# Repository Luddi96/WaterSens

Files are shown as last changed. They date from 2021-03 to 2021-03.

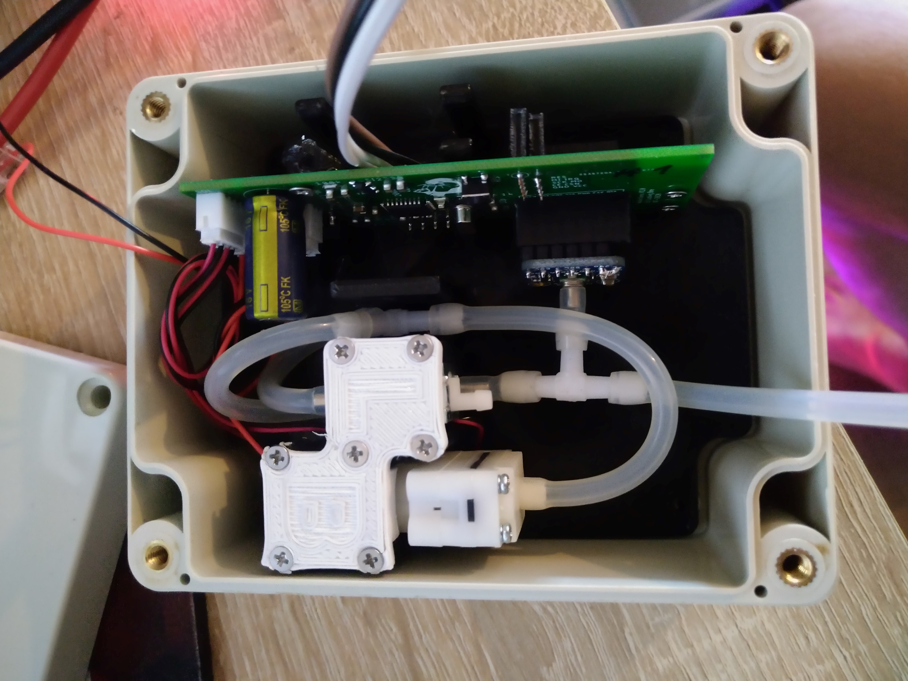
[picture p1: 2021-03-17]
Images/IMG_20200821_111729.jpg

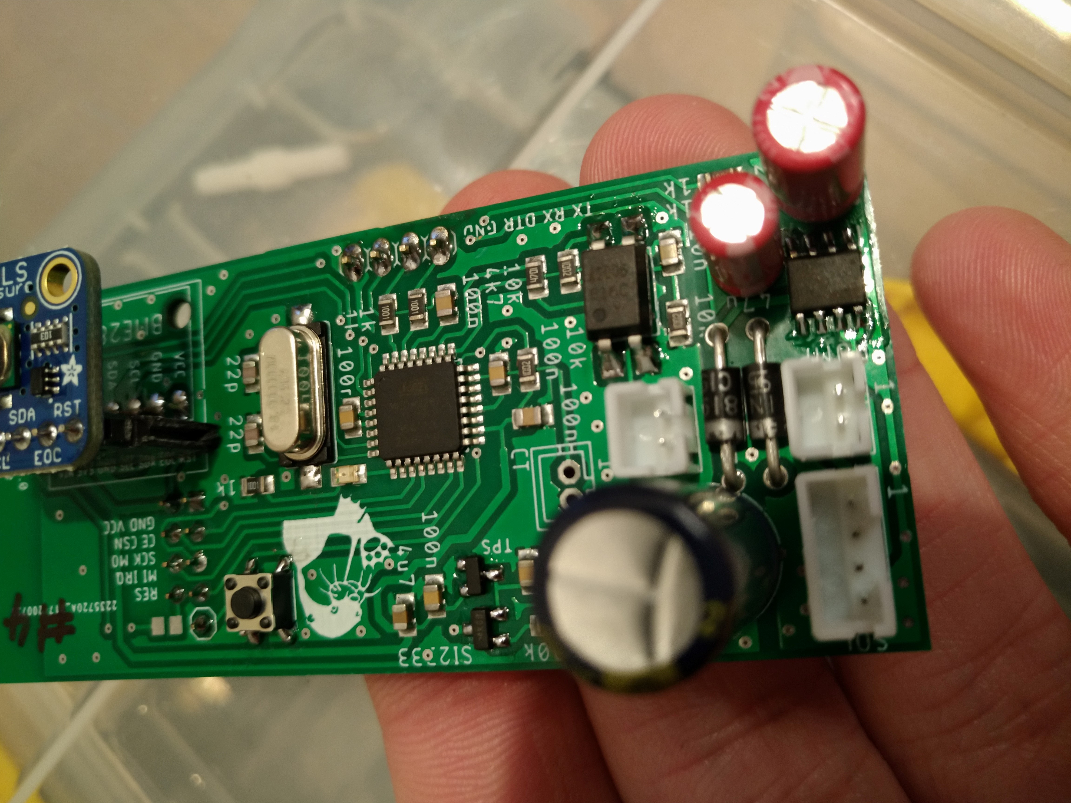
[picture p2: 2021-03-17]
Images/IMG_20210317_152724.jpg

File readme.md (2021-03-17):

Universaler Zisternen-Füllstandsmesser

Einleitung:

Jeder Besitzer einer Regenzisterne kennt diese Frage: Wie viel Wasser verbleibt mir noch und wie viel hat der letzte Regen wieder aufgefüllt? Um Abhilfe zu schaffen gibt es eine Reihe an Messgeräten und Sensoren: Ganz simpel mit mehren Elektroden auf verschiedenen Höhen, kapazitiv unter Zuhilfenahme der Dielektrizitätskonstante des Wassers selbst, per Ultraschall oder per Druckmessung. Einige dieser Messungen haben Vorteile gegenüber anderen. In diesem Beitrag möchte ich Ihnen eine Methode zur Messung vorstellen, welche weder durch Temperatur, Luftdruck oder Leitfähigkeit des Wassers verfälscht wird und außerdem selbstreinigend (wartungsfrei) agiert. Die Messgenauigkeit liegt bei umgerechnet 20 Liter in einer 7500 Liter Zisterne, also etwa 0,3%!
Das Projekt involviert die Programmierung eines ATMega Mikrocontrollers, das Löten von SMD Bauteilen (es könnte aber auch als THT aufgebaut werden) sowie grundlegende mechanische Fähigkeiten.
Das Funktionsprinzip:
Wie funktioniert der Sensor? Im Prinzip ganz einfach: Man misst den Druck, den das Wasser an der tiefsten Stelle der Zisterne erzeugt. Dieser ist proportional zur Höhe des Wassers und somit (bei einer gleichförmigen Zisterne) ebenfalls proportional zum Füllstand. Würde man aber einfach einen Sensor auf den Grund der Zisterne herablassen, so stößt man auf 3 Probleme: 1. Solche Sensoren sind recht teuer (müssen ja auch wasserdicht sein) 2. Es gibt keine Möglichkeit, den Sensor periodisch zu nullen 3. Der Luftdruck beeinflusst das Ergebnis: 10hPa Druckunterschied bedeuten bereits 100mm Wassersäule oder einen Messfehler von etwa 750 Liter in bzw. 10% in einer 7500 Liter Zisterne.
Mit einem Trick können aber alle der eben genannten Einflüsse kompensiert werden: In die Zisterne wird lediglich ein dünner Schlauch mit einem Gewicht am offenen Ende eingeführt und bis zum Boden herabgelassen. In das andere Ende wird mit einer kleinen Luftpumpe so lange Luft gepumpt, bis dieser komplett gefüllt ist und erste Luftblasen austreten. Der Druck im Schlauch entspricht dann genau dem Druck am Boden der Zisterne. Mit einem empfindlichen Drucksensor kann dieser dann ausgelesen werden. Wenn der Schlauch vor und nach der Messung mittels einem Magnetventil entleert wird, können Umgebungsdruck und Langzeit-Drift des Drucksensor eliminiert werden. Ebenso ist das System durch das "Ausspülen" des Schlauches bei jeder Messung selbstreinigend.

Komponenten:

1x Miniatur-Luftpumpe JQB031 oder ähnlich https://bit.ly/2ENsoDM
2x 3-Wege Magnetventil DQF2-6A-4 von dyxminipump https://bit.ly/2G6OzFo
1x Schlauch-Verbinder-Sortiment https://bit.ly/31LYU29
1x 50cm Silikonschlauch (2mm ID) https://bit.ly/2QGRM0I
1x 5m Silikonschlauch (4mm ID) https://bit.ly/34PzMJN
1x MPRLS Sensor-Modul https://www.adafruit.com/product/3965
1x Funkmodul, z.B. NRF24L01
1x Hauptleiterplatte, BOM als ZIP im Anhang
1x LiPo Einzelzelle 1000mAh https://bit.ly/2EHX8WZ

Aufbau:

Die Ansteuerung der Pumpe und Magnetventile sowie das Auslesen und Auswerten des Drucksensor und das anschließende Versenden der Daten per Funk übernimmt die Hauptleiterplatte. Auf dieser befindet sich ein ATMega328P-AU, geflasht mit dem Arudino Nano Bootloader. Zur Ansteuerung der Aktoren genügt ein IRF7103. Da der Sensor mehrere Jahre ohne Batteriewechsel auskommen soll, wird zur Spannungsversorgung ein TPS7A05 LDO mit einer Ausgangsspannung von 3,3V und einem Eigenstromverbrauch von nur 1uA verbaut. Auch der Spannungsteiler zur Messung der Batteriespannung wird über einen Optokoppler geschalten. So kommt das Gesamtsystem auf 6uA Sleep-Strom und bis zu 2 Jahre Lebensdauer bei 2 Messungen am Tag.
Die Pumpe sowie Magnetventile werden wie folgt verbunden:

Mit dem ersten Magnetventil kann der Druck aus dem System abgelassen werden, das andere Magnetventil schneidet "Messschlauch" und Drucksensor vom Rest ab, um einen Druckabfall während der Messung zu verhindern.
Das ganze wird auf einem 3D-Druck-Träger (.stl in der zip-Datei enthalten) in ein Modulgehäuse wasserdicht eingebaut. Der Druckausgleich wird mit einem Druckausgleichselement erreicht.
In der Software sieht der Ablauf wie folgt aus:
Initialisierung: Ports, Variablen, etc. initialisieren, Sensorwert auf 0 setzen
Start einer Messung:
-Druck im offenen System 3x messen, Wert als "before" speichern
-Magnetventil 1 schließen, Pumpe aktivieren
-Nach bestimmter Zeit Magnetventil 2 schließen, Pumpe abschalten und Magnetventil 1 wieder öffnen (der Schlauch steht jetzt unter Druck)
-Druck 3x messen, Wert als "high" speichern
-Magnetventil 2 öffnen und Druck entweichen lassen
-Druck 3x messen und als "after" speichern
-Aus before, after und high die Druckdifferenz berechnen, das ist das Ergebnis.
Eine solche Messung dauert etwa 8 Sekunden.
Fazit und Ergebnisse:
Ich habe das System nun schon seit 2 Monaten in Betrieb. Um die Haltbarkeit zu testen habe ich den Messintervall auf 60 Sekunden verringert und insgesamt hat das System bereits über 25.000 Messungen durchgeführt - ohne Probleme. Die Standardabweichung der Messung liegt bei etwa 2,5mm Wassersäule oder 20 Liter bei einer 7500 Liter Zisterne. Mir gefällt das System sehr gut. Ich habe bereits ein weiteres System gebaut, welches bei einem Bekannten eingebaut wird. Dort ersetzen wir das Funkmodul durch ein LAN-Modul, das System wird zudem dauerhaft mit Strom versorgt.

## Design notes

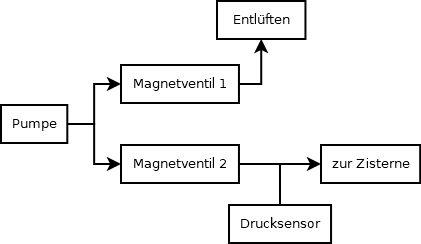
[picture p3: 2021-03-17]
Documentation/Schema.png

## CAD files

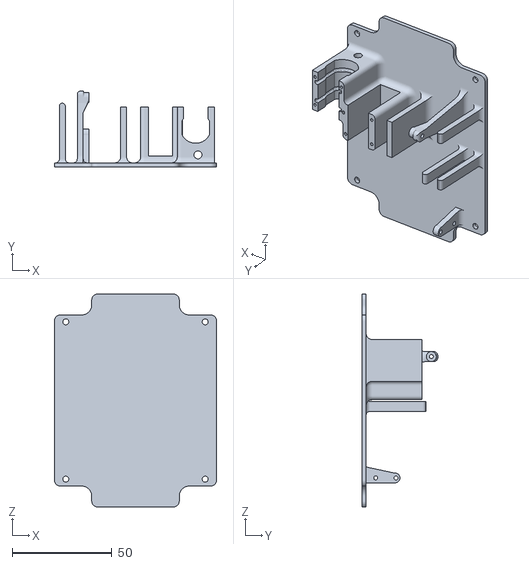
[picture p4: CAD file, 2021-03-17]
Documentation/WaterSensor_V1-1_basic.stl
81.5 x 38.0 x 107.0

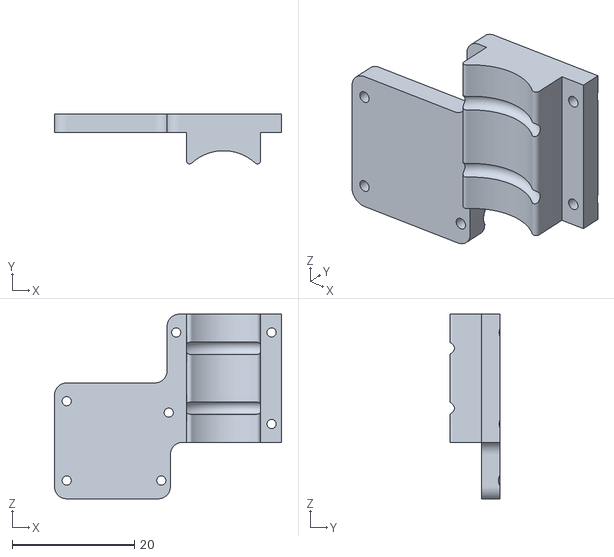
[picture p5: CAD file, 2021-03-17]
Documentation/WaterSensor_V1-0_basic_lid.stl
37.2 x 8.18 x 30.3

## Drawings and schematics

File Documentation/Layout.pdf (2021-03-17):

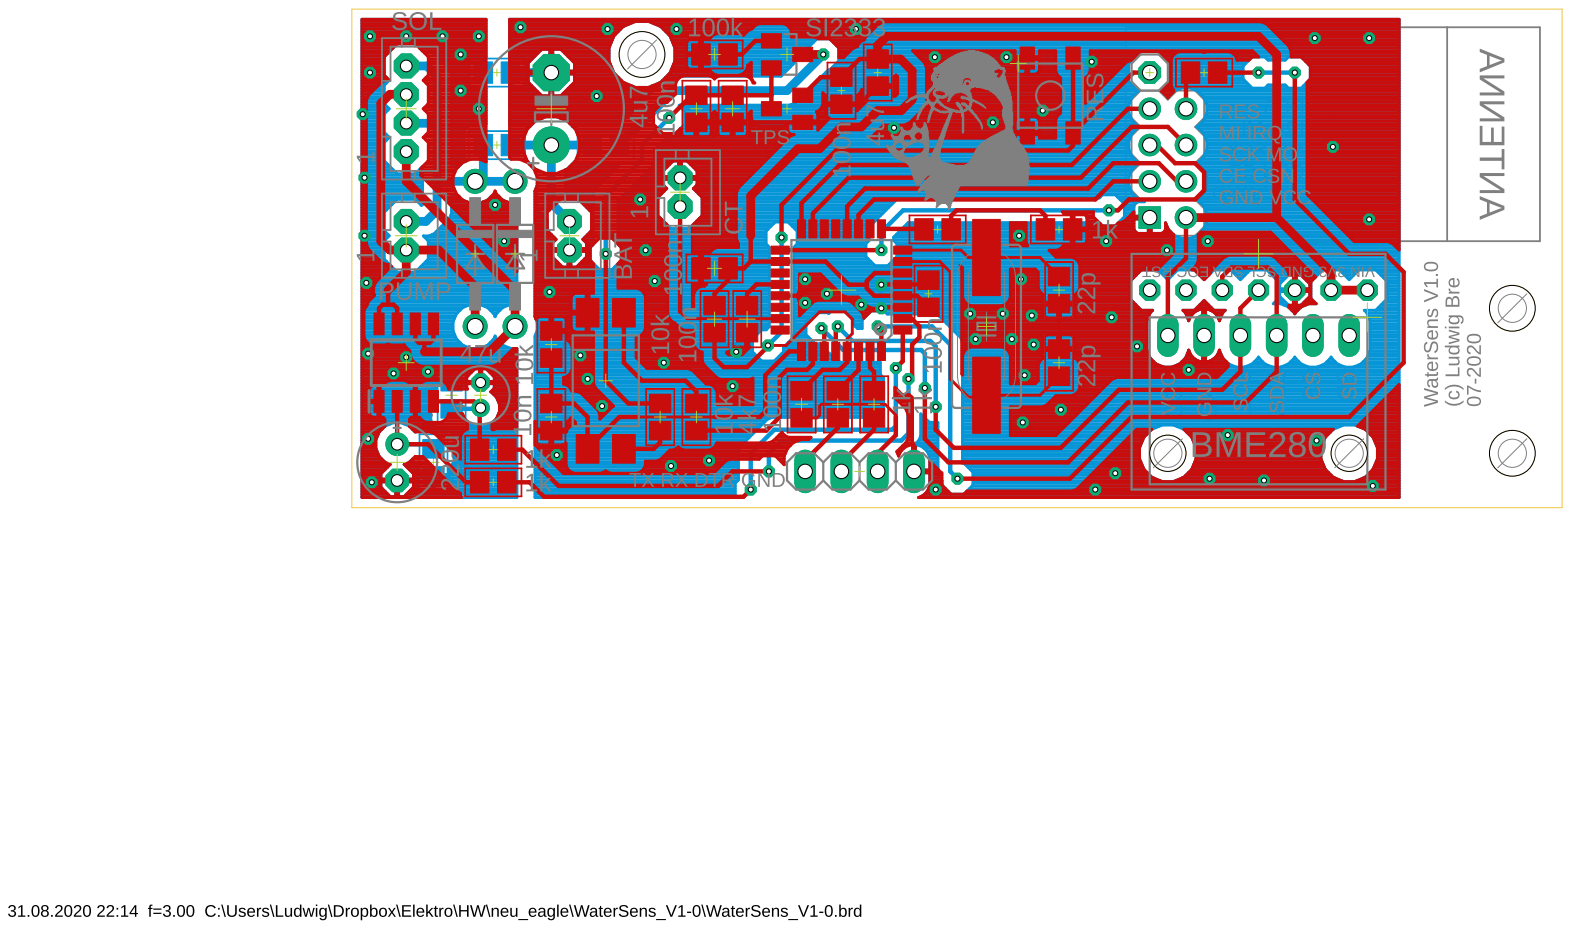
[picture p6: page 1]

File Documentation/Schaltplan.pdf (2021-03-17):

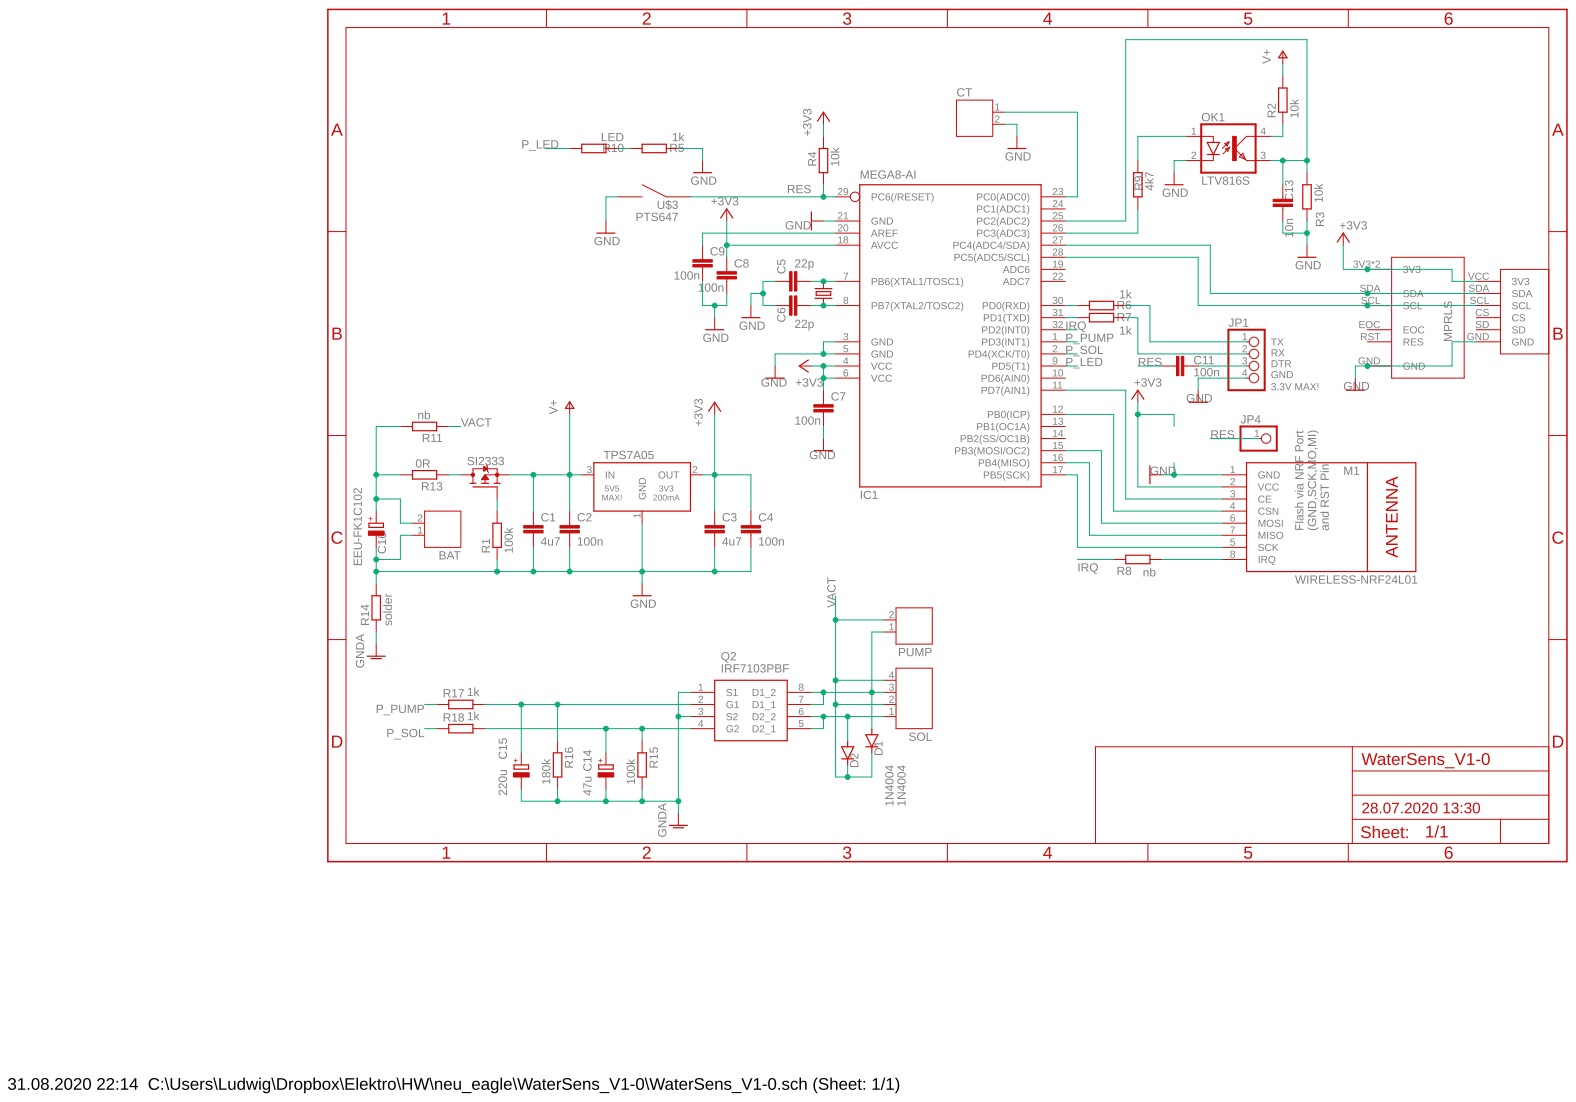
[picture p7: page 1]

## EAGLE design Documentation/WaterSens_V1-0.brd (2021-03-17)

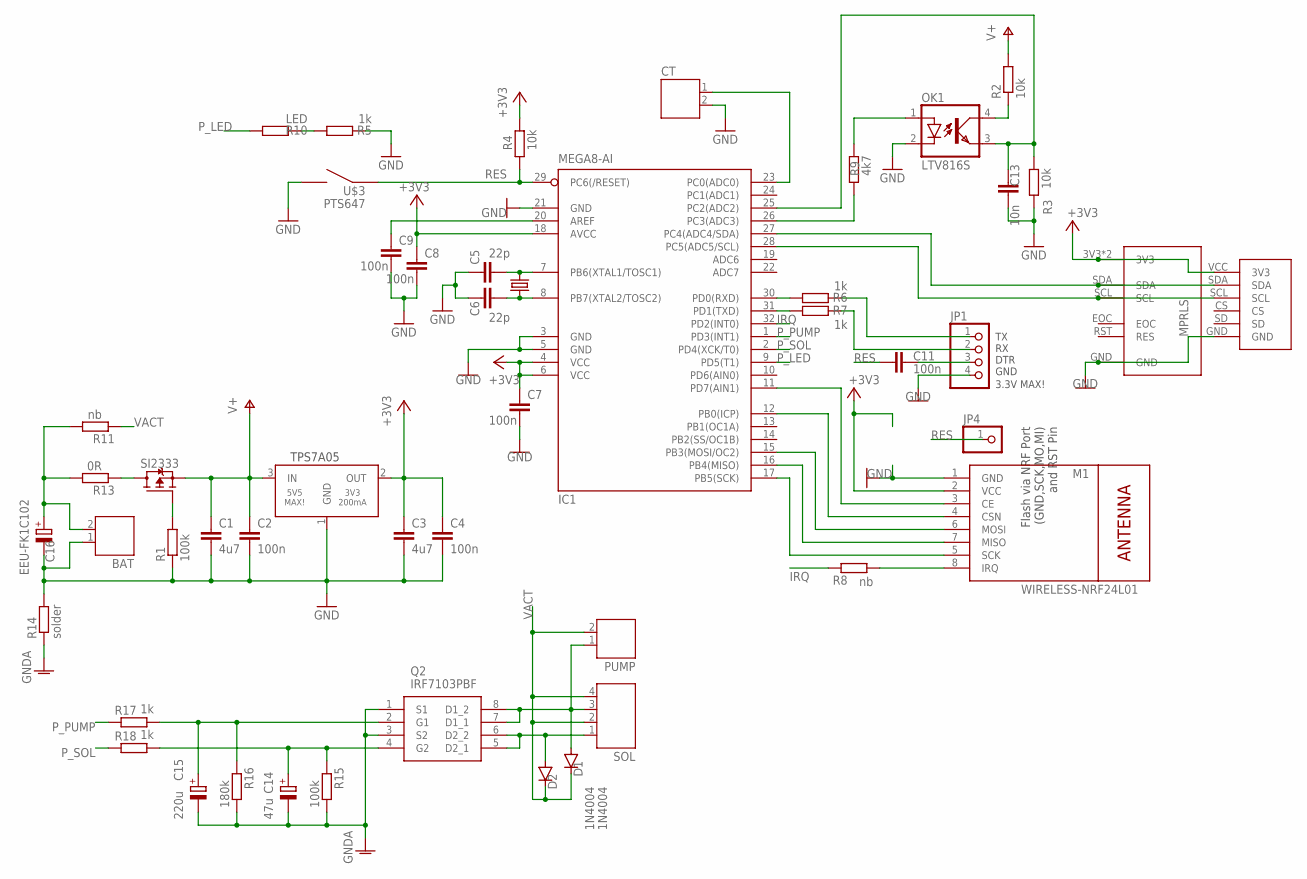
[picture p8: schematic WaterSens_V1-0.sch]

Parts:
BAT: JST-PH2
C1, C3: 4u7; C0805
C2, C4, C7, C8, C9, C11: 100n; C0805
C5, C6: 22p; C0805
C13: 10n; C0805
C14: 47u; E1,8-4
C15: 220u; E2,5-6E
C16: EEU-FK1C102; E5-10,5
CT: JST-PH2
D1, D2: 1N4004; DO41-10
IC1: MEGA8-AI; TQFP32-08
JP1: PINHD-1X4; 1X04
JP4: PINHD-1X1; 1X01
M1: WIRELESS-NRF24L01
OK1: LTV816S; DIL4-SMD
PUMP: JST-PH2
Q1: CRYSTALHC49UP; HC49UP
Q2: IRF7103PBF; SOIC127P600X175-8N
R1, R15: 100k; R0805
R2, R3, R4: 10k; R0805
R5, R6, R7, R17, R18: 1k; R0805
R8, R11: nb; R0805
R9: 4k7; R0805
R10: LED; R0805
R13: 0R; R0805
R14: solder; R0805
R16: 180k; R0805
SOL: JST-PH4
U$1: MPRLS_ADA
U$2: TEMP-HUM-PRES-BME280-3V3
U$3: PTS647
U$5: TPS7A05; SOT23
U$6: SI2333; SOT23

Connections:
+3V3: C3.1, C4.1, C7.1, C8.1, IC1.4 (VCC), IC1.6 (VCC), IC1.18 (AVCC), M1.2 (VCC), R4.2, U$1.3V3, U$1.VIN (3V3), U$2.VCC (3V3), U$5.2 (OUT)
GND: BAT.1, C1.2, C2.2, C3.2, C4.2, C5.1, C6.1, C7.2, C8.2, C9.2, C13.1, C16.-, CT.2, IC1.3 (GND), IC1.5 (GND), IC1.21 (GND), JP1.4, M1.1 (GND), OK1.2 (C), R1.1, R3.1, R5.1, R14.2, U$1.GND, U$2.GND, U$3.3, U$3.4, U$5.1 (GND)
GNDA: C14.-, C15.-, Q2.1 (S1), Q2.3 (S2), R14.1, R15.2, R16.2
IRQ: IC1.32 (PD2(INT0)), R8.2
unnamed: IC1.27 (PC4(ADC4/SDA)), U$1.SDA, U$2.SDA
unnamed: IC1.28 (PC5(ADC5/SCL)), U$1.SCL, U$2.SCL
unnamed: BAT.2, C16.+, R11.2, R13.2
unnamed: C5.2, IC1.7 (PB6(XTAL1/TOSC1)), Q1.2
unnamed: R1.2, U$6.1 (G)
unnamed: OK1.4 (COL), R2.1
unnamed: C14.+, Q2.4 (G2), R15.1, R18.2
unnamed: C15.+, Q2.2 (G1), R16.1, R17.2
unnamed: IC1.26 (PC3(ADC3)), R9.1
unnamed: C6.2, IC1.8 (PB7(XTAL2/TOSC2)), Q1.1
unnamed: IC1.11 (PD7(AIN1)), M1.3 (CE)
unnamed: IC1.30 (PD0(RXD)), R6.2
unnamed: C9.1, IC1.20 (AREF)
unnamed: OK1.1 (A), R9.2
unnamed: IC1.31 (PD1(TXD)), R7.2
unnamed: JP1.1, R6.1
unnamed: JP1.2, R7.1
unnamed: C11.2, JP1.3
unnamed: IC1.12 (PB0(ICP)), M1.4 (CSN)
unnamed: IC1.15 (PB3(MOSI/OC2)), M1.6 (MOSI)
unnamed: IC1.16 (PB4(MISO)), M1.7 (MISO)
unnamed: IC1.17 (PB5(SCK)), M1.5 (SCK)
unnamed: M1.8 (IRQ), R8.1
unnamed: R5.2, R10.1
unnamed: R13.1, U$6.3 (D)
unnamed: D1.A, PUMP.1, Q2.7 (D1_1), Q2.8 (D1_2), SOL.3
unnamed: D2.A, Q2.5 (D2_1), Q2.6 (D2_2), SOL.1
unnamed: CT.1, IC1.23 (PC0(ADC0))
P_LED: IC1.9 (PD5(T1)), R10.2
P_PUMP: IC1.1 (PD3(INT1)), R17.1
P_SOL: IC1.2 (PD4(XCK/T0)), R18.1
RES: C11.1, IC1.29 (PC6(/RESET)), JP4.1, R4.1, U$3.1, U$3.2
U_MESS: C13.2, IC1.25 (PC2(ADC2)), OK1.3 (EMIT), R3.2
V+: C1.1, C2.1, R2.2, U$5.3 (IN), U$6.2 (S)
VACT: D1.C, D2.C, PUMP.2, R11.1, SOL.2, SOL.4

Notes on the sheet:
TX RX DTR GND
3.3V MAX!
TPS7A05
Flash via NRF Port (GND,SCK,MO,MI) and RST Pin

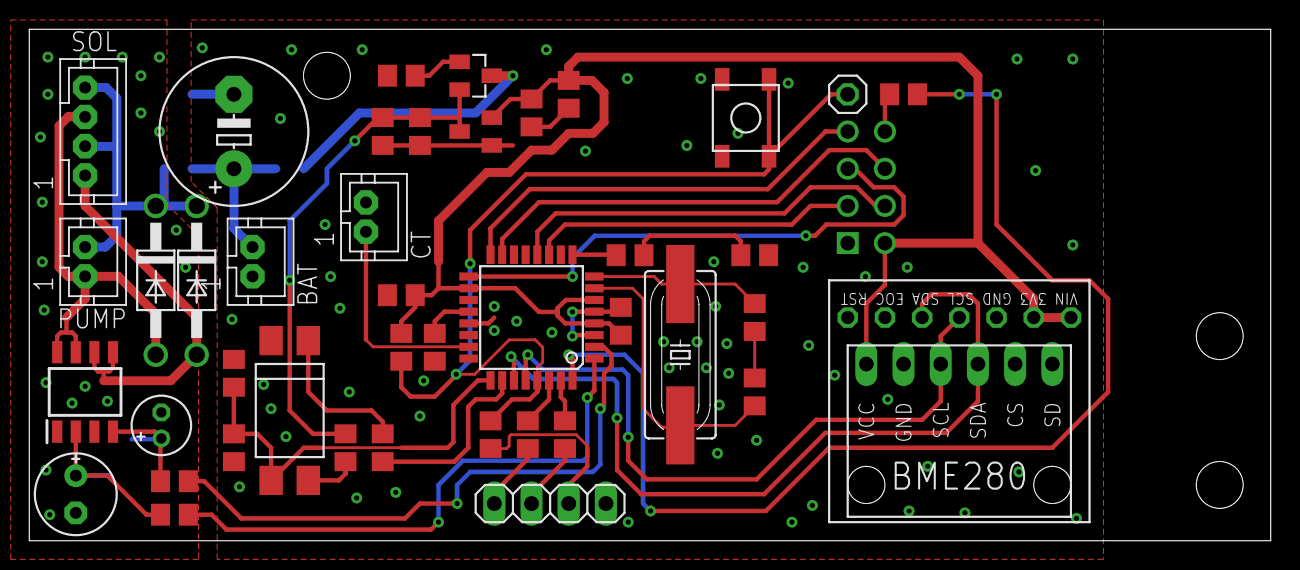
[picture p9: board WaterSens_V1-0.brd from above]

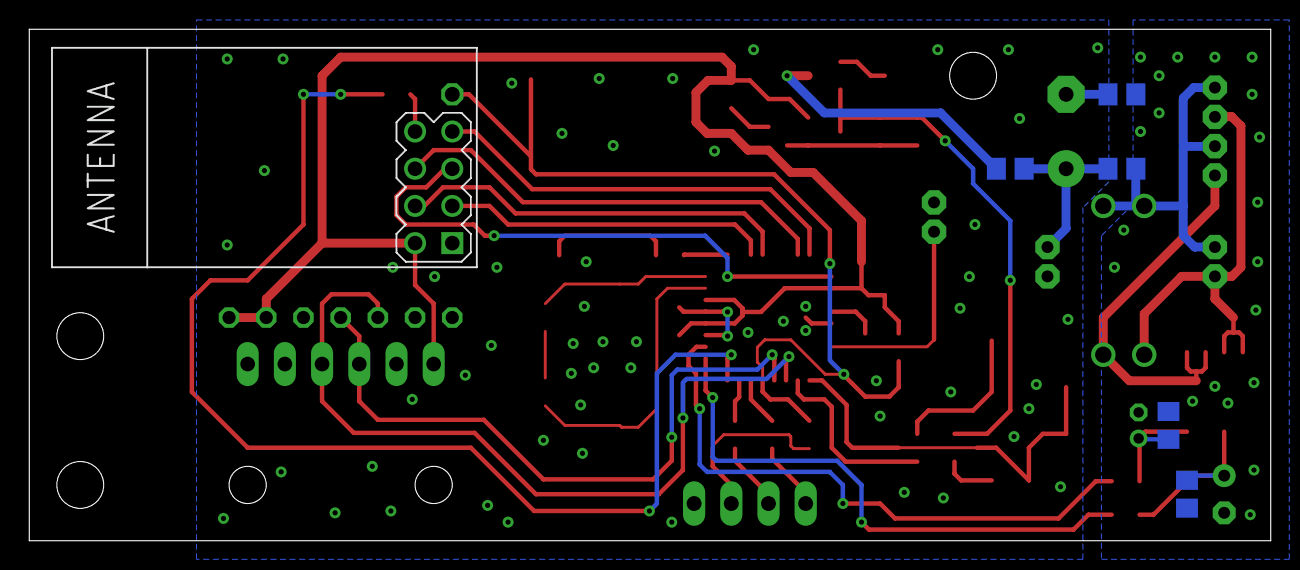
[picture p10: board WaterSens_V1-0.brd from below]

Board: 2 copper layers, 84.8 x 34.9 mm, 49 parts (6 on the bottom side), 39 nets.

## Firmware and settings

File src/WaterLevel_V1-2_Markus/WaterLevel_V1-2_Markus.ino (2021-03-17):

//Cables: 19cm / 15cm

/**Includes**/
#include <Wire.h> //Needed for BME
#include <SPI.h> //Needed for NRF
#include <nRF24L01.h> //Needed for NRF
#include <RF24.h> //Needed for NRF
#include <Adafruit_Sensor.h> //Needed for BME
#include <Adafruit_BME280.h> //Needed for BME
#include "Adafruit_MPRLS.h" //Needed for MPRLS

/**Pin Assignment**/
#define P_NRF_CE 7 //CE of NRF Module
#define P_NRF_CSN 8 //CSN of NRF Module
#define P_UBAT_EN A3 //This pin enables UBAT measurement (approx. 200uA)
#define P_UBAT_MEAS A2 //Analog pin to read UBAT via divider
#define P_LED_USER 5 //Led for button illumination (approx. 20mA)
#define P_SOL 4 //Solenoid enable (approx. 400mA)
#define P_PUMP 3 //Pump enable (approx. 600mA)

#define T20TO6 1
#define T6TO13 2
#define T13TO20 3

/**Adress definition**/
#define A_BME_I2C 0x76
#define A_MPRLS_I2C 0x18
#define A_BROADC "0XXXX"
#define MODULE_ID 0xA2

/**Instance creation**/
RF24 radio(P_NRF_CE, P_NRF_CSN);
Adafruit_BME280 bme;
Adafruit_MPRLS mpr = Adafruit_MPRLS(-1,-1);

/**Global variables**/
uint8_t txAddr[6] = {A_BROADC};
uint8_t rxAddr[6] = {A_BROADC};
float volt = 0;
float mprlsOffset = 0.0;
int errCnt = 0;

int timestep = T20TO6;

//#define M_VERB 1 //Verbose meas output
//#define S_VERB 1 //Verbose sys output
//#define S_VERB2 1 //Very Verbose sys output

/**Functions**/
void initReg();
void initPins();
void initNRF();
void initBME();
void initMPR();
void deepSleep(long duration);
uint8_t measUBat();

bool checkMprlsStatus();
float measMprlsLevel(float offset);
void setMprlsZero(int num);
float measDepth(int cnt);
int reResp = 0;


void setup() {

  #ifdef S_VERB
  Serial.begin(9600);
  while (!Serial) //Wait for serial
  {
  }
  Serial.println("\n\n\nReset!");
  #endif
  rxAddr[0] = MODULE_ID;
  initReg();
  initPins();
  initNRF();
  initBME();
  initMPR();
}

unsigned long after = 0;
unsigned long before = 0;
unsigned long before2 = 0;

void loop() {

  //Messen
  float dpt = 0.0;
  dpt = measDepth(1);
  //Ausgeben
  Serial.println(dpt);
  //1 Stunde warten
  delay(3600000);
}

/** Functions **/

/* Set all registers for operation */
void initReg()
{
  #ifdef S_VERB
  Serial.print("Setting register...");
  #endif
  WDTCSR = (24); //change enable and WDE - also resets
  WDTCSR = (33); //prescalers only - get rid of the WDE and WDCE bit
  WDTCSR |= (1<<6); //enable interrupt mode

  //Disable ADC - don't forget to flip back after waking up if using ADC in your application ADCSRA |= (1 << 7);
  //ADCSRA &= ~(1 << 7);
  
  //ENABLE SLEEP - this enables the sleep mode
  SMCR |= (1 << 2); //power down mode
  SMCR |= 1;//enable sleep
  #ifdef S_VERB
  Serial.println("Done");
  #endif
}

/* Init all Pins */
void initPins()
{
  pinMode(P_UBAT_EN, OUTPUT);
  pinMode(P_LED_USER, OUTPUT);

  pinMode(P_SOL, OUTPUT);
  digitalWrite(P_SOL, LOW);
  
  pinMode(P_PUMP, OUTPUT);
  digitalWrite(P_PUMP, LOW);
}

/*Init NRF Module */
void initNRF()
{
  #ifdef S_VERB
  Serial.print("Enabling NRF...");
  #endif
  radio.begin();
  radio.stopListening();
  radio.openReadingPipe(1,rxAddr);
  radio.openWritingPipe(txAddr);
  #ifdef S_VERB
  Serial.println("Done");
  #endif
}

/* Init BME Module */
void initBME()
{
  #ifdef S_VERB
  Serial.print("Enabling BME...");
  #endif
  bme.begin(A_BME_I2C, &Wire);
  bme.setSampling(Adafruit_BME280::MODE_FORCED,
                    Adafruit_BME280::SAMPLING_X1, // temperature
                    Adafruit_BME280::SAMPLING_X1, // pressure
                    Adafruit_BME280::SAMPLING_X1, // humidity
                    Adafruit_BME280::FILTER_OFF   );
  #ifdef S_VERB
  Serial.println("Done");
  #endif
}

/* Deep sleep for approx. (duration*8.75) seconds */
void deepSleep(int duration)
{
  #ifdef S_VERB
  Serial.println("Going to sleep...");
  delay(200);
  Serial.end();
  #endif
  //digitalWrite(P_UBAT_EN, LOW); //Diable UBAT Meas
  radio.powerDown(); //Disable NRF
  ADCSRA &= ~(1 << 7); //Disable ADC
  //Actual sleep
  for(long i = 0; i < duration; i++)
  {
    //BOD DISABLE - this must be called right before the __asm__ sleep instruction
    MCUCR |= (3 << 5); //set both BODS and BODSE at the same time
    MCUCR = (MCUCR & ~(1 << 5)) | (1 << 6); //then set the BODS bit and clear the BODSE bit at the same time
    __asm__  __volatile__("sleep");//in line assembler to go to sleep
  }
  //Actual wake up
  delay(1);
  #ifdef S_VERB
  Serial.begin(9600);
  while (!Serial) //Wait for serial
  {
  }
  Serial.println("Woke up...");
  #endif
  ADCSRA |= (1 << 7); //Enable ADC
  radio.powerUp(); //Enable NRF
  //digitalWrite(P_UBAT_EN, HIGH); //Enable UBAT Meas
}

/* Measure UBat and give back percent */
uint8_t measUBat()
{
  digitalWrite(P_UBAT_EN, HIGH); //Enable UBAT Meas
  delay(5);
  #ifdef S_VERB2
  Serial.println("Measuring UBat...");
  #endif
  float rawValue = 0;
  for(int i = 0; i < 3; i++)
  {
    delay(1);
    rawValue += analogRead(P_UBAT_MEAS);
  }
  digitalWrite(P_UBAT_EN, LOW); //Diable UBAT Meas
  volt = rawValue / 3072.0 * 6.6 * 1.025586;
  float offsVolt = volt - 3.3;
  if(offsVolt > 1.2) offsVolt = 1.2;
  if(offsVolt < 0.0) offsVolt = 0.0;
  float fPercent = -(13.27 * pow(offsVolt,5)) - (37.49 * pow(offsVolt,4)) + (57.53 * pow(offsVolt,3)) + (42.27 * pow(offsVolt,2)) + (44.17 * offsVolt) - 1.9;
  if(fPercent > 100.0) fPercent = 100.0;
  if(fPercent < 0.00) fPercent = 0.0;
  uint8_t percent = round(fPercent);
  
  #ifdef S_VERB2
  Serial.print("UBat: ");
  Serial.print(volt);
  Serial.print("V, Percent: ");
  Serial.print(percent);
  Serial.println("%\n");
  #endif

  return percent;
}

/* Check MPRLS Status (deprecated) */
bool checkMprlsStatus()
{
  return 1;
}

/*Measure current pressure and return water level equivalent */
float measMprlsLevel(float offset)
{
  int scnt = 0;
  begMeas:
  if(1)
  {  
    float psi =  mpr.readPressure() / 68.947572932;
    if( (psi * 703.06957829636) > 20000 || (psi * 703.06957829636) < -1000)
    {
      scnt ++;
      errCnt++;
      if(scnt > 10)
      {
        #ifdef M_VERB
        Serial.println("!!!REMEASURE FAIL!!!");
        #endif
        return -99999;
      }
      else
      {
        #ifdef M_VERB
        Serial.println("!!!REMEASURE!!!");
        #endif
        delay(100);
        goto begMeas;
      }
    }
    else
    {
      return (psi * 703.06957829636)-offset;
    }
  }
}

/* Init MPRLS Sensor */
void initMPR()
{
  #ifdef S_VERB
  Serial.print("Enabling MPR...");
  #endif
  
  if (! mpr.begin()) 
  {
    Serial.println("Failed to communicate with MPRLS sensor, check wiring?");
    while (1) 
    {
      delay(1000);
      Serial.println("Failed to communicate with MPRLS sensor, check wiring?");
    }
  }
  delay(100);
  setMprlsZero(10);

  #ifdef S_VERB
  Serial.println("Done");
  #endif
}

/* Get offset and save to global offset variable */
void setMprlsZero(int num)
{
  for(int i = 0; i < num; i++)
  {
    measMprlsLevel(0.0);
    delay(100);
  }
  float offs = measMprlsLevel(0.0);
  delay(100);
  offs += measMprlsLevel(0.0);
  delay(100);
  offs += measMprlsLevel(0.0);
  offs /= 3.0;
  mprlsOffset = offs;
  delay(100);
}

/* Activate pump and solenoids to get water heigt (temp. drift compensated) */
float measDepth(int cnt)
{
  float before[cnt];
  float top[cnt];
  float aftr[cnt];

  int pump_delay = 20;
  int settle_delay = 10;
  int switchover_delay = 1;
  int empty_delay = 50;
  int safecnt = 0;
  
  setMprlsZero(5);
  
  digitalWrite(P_SOL, LOW);
    
  for(int i = 0; i < cnt; i++)
  {
    #ifdef M_VERB
    Serial.println(-20);
    #endif
    //Get 0 press
    before[i] = measMprlsLevel(mprlsOffset)/3.0;
    delay(100);
    before[i] += measMprlsLevel(mprlsOffset)/3.0;
    delay(100);
    before[i] += measMprlsLevel(mprlsOffset)/3.0;
    delay(100);

    safecnt = 0;
    while(before[i] > 3000 || before[i] < -1000)
    {
      #ifdef M_VERB
      Serial.println("Retry measure");
      #endif
      //Get 0 press
      before[i] = measMprlsLevel(mprlsOffset)/3.0;
      delay(100);
      before[i] += measMprlsLevel(mprlsOffset)/3.0;
      delay(100);
      before[i] += measMprlsLevel(mprlsOffset)/3.0;
      delay(100);
      safecnt++;
      if(safecnt == 10)
      {
        #ifdef M_VERB
        Serial.println("Error measure");
        #endif
        before[i] = 0;
      }
    }
    
    digitalWrite(P_PUMP, HIGH);

    //Wait for pump
    for(int i = 0; i < pump_delay; i++)
    {
      #ifdef M_VERB
      Serial.println(measMprlsLevel(mprlsOffset));
      #else
      measMprlsLevel(mprlsOffset);
      #endif
      delay(100);
    }
  
    digitalWrite(P_SOL, HIGH);
    
    for(int i = 0; i < switchover_delay; i++)
    {
      #ifdef M_VERB
      Serial.println(measMprlsLevel(mprlsOffset));
      #else
      measMprlsLevel(mprlsOffset);
      #endif
      delay(100);
    }
    
    digitalWrite(P_PUMP, LOW);

    //Wait for pressure to settle after pump
    for(int i = 0; i < settle_delay; i++)
    {
      #ifdef M_VERB
      Serial.println(measMprlsLevel(mprlsOffset));
      #else
      measMprlsLevel(mprlsOffset);
      #endif
      delay(100);
    }
    
    #ifdef M_VERB
    Serial.println(-20);
    #endif
    
    //Get top press
    top[i] = measMprlsLevel(mprlsOffset)/3.0;
    delay(100);
    top[i] += measMprlsLevel(mprlsOffset)/3.0;
    delay(100);
    top[i] += measMprlsLevel(mprlsOffset)/3.0;
    delay(100);

    safecnt = 0;
    while(top[i] > 3000 || top[i] < -1000)
    {
      #ifdef M_VERB
      Serial.println("Retry measure");
      #endif
      //Get top press
      top[i] = measMprlsLevel(mprlsOffset)/3.0;
      delay(100);
      top[i] += measMprlsLevel(mprlsOffset)/3.0;
      delay(100);
      top[i] += measMprlsLevel(mprlsOffset)/3.0;
      delay(100);
      safecnt++;
      if(safecnt == 10)
      {
        #ifdef M_VERB
        Serial.println("Error measure");
        #endif
        top[i] = 0;
      }
    }
    
    digitalWrite(P_SOL, LOW);
    //Wait for pressure to go back to 0
    for(int i = 0; i < empty_delay; i++)
    {
      #ifdef M_VERB
      Serial.println(measMprlsLevel(mprlsOffset));
      #else
      measMprlsLevel(mprlsOffset);
      #endif
      delay(100);
    }
    
    #ifdef M_VERB
    Serial.println(-20);
    #endif
    
    //Get 0 press after
    aftr[i] = measMprlsLevel(mprlsOffset)/3.0;
    delay(100);
    aftr[i] += measMprlsLevel(mprlsOffset)/3.0;
    delay(100);
    aftr[i] += measMprlsLevel(mprlsOffset)/3.0;
    delay(100);

    safecnt = 0;
    while(aftr[i] > 3000 || aftr[i] < -1000)
    {
      #ifdef M_VERB
      Serial.println("Retry measure");
      #endif
      //Get 0 press after
      aftr[i] = measMprlsLevel(mprlsOffset)/3.0;
      delay(100);
      aftr[i] += measMprlsLevel(mprlsOffset)/3.0;
      delay(100);
      aftr[i] += measMprlsLevel(mprlsOffset)/3.0;
      delay(100);
      safecnt++;
      if(safecnt == 10)
      {
        #ifdef M_VERB
        Serial.println("Error measure");
        #endif
        aftr[i] = 0;
      }
    }
    
  }
  
  float res = 0;
  for(int i = 0; i < cnt; i++)
  {
    res += top[i] - (before[i] + (((aftr[i]-before[i])/(float)(pump_delay+settle_delay+switchover_delay))*(float)empty_delay));//top[i]-((aftr[i] + before[i])/2.0); //top[i]-( before[i] + (aftr[i]-before[i])*( (float)(settle_delay+pump_delay)/5.0 ) );// top[i] - (before[i] + ((aftr[i]-before[i])/(float)(pump_delay+settle_delay+switchover_delay))*(float)empty_delay
    //res += top[i] - (before[i] + (aftr[i]-before[i])/2.0);
    #ifdef M_VERB
      Serial.println("top: " + String(top[i]) + " before: " + String(before[i]) + "aftr: " + String(aftr[i]));
    #endif
  }
  res /= cnt;
  return res;
}

uint8_t msb(uint16_t input)
{
  return (input >> 8 ) & 0xFF;
}
uint8_t lsb(uint16_t input)
{
  return input & 0xFF;
}

/* Leave this untouched */
ISR(WDT_vect) 
{
}

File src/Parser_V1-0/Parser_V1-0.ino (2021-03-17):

#include <SPI.h>
#include <nRF24L01.h>
#include <RF24.h>

#include <ESP8266WiFi.h>
#include <WiFiClient.h> 
#include <ESP8266WebServer.h>
#include <ESP8266HTTPClient.h>

RF24 radio(D4, D8); // CE, CSN

uint8_t rxAddr[6] = {"0XXXX"}; //Adress of this Node
uint8_t txAddr[6] = {"5XXXX"}; //Adress of Node5

const char *ssid = "XXXX";  //ENTER YOUR WIFI SETTINGS
const char *password = "XXXX";

uint16_t getRemain(uint8_t mod_id);

void setup() 
{
  Serial.begin(9600);
  radio.begin();
  radio.setDataRate(RF24_250KBPS);
  radio.stopListening();
  //radio.openWritingPipe(txAddr);
  radio.openReadingPipe(1,rxAddr);

  WiFi.mode(WIFI_OFF);        
  delay(1000);
  WiFi.mode(WIFI_STA);        
  
  WiFi.begin(ssid, password);     
  Serial.println("");
  Serial.print("Connecting");
  
  while (WiFi.status() != WL_CONNECTED) 
  {
    delay(500);
    Serial.print(".");
  }
  Serial.println("\n\nGO!");
}

int16_t zwerg = 0;
float fzwerg = 0;
uint16_t tx_remain = 4186;

char mod_id = 0x00;
uint8_t tx_arr[] = {0x00, 0x00, 0x0E, 0x00, 0x02, 0xFF};

void loop() 
{
  String valToSend = "?INI=1";
  radio.startListening();
  if(radio.available())
  {    
    Serial.println("");
    Serial.println("_____________");
    Serial.println("Hex Rep:");
    
    uint8_t rcv_arr[35];
    for(int i = 0; i < 35; i++)
    {
      rcv_arr[i] = 0;
    }
    
    radio.read(&rcv_arr, sizeof(rcv_arr));
    
    for(int i = 0; i < 35; i++)
    {
      Serial.print(rcv_arr[i], HEX);
      Serial.print(", ");
    }
    
    Serial.println("");
    Serial.println("_____________");
    Serial.println("Decode:");

    bool rcvCorr = 0;
    for(int i = 0; i < 35; i++)
    {
      switch (rcv_arr[i])
      {
        case 0x00:  i++;
                    Serial.print("Mod ID: ");
                    Serial.println(rcv_arr[i],HEX);
                    mod_id = rcv_arr[i];
                    valToSend += "&MOD=" + String(mod_id, HEX);
                    break;
        case 0x01:  i+=2;
                    zwerg = (rcv_arr[i] | (rcv_arr[i-1] << 8));
                    fzwerg = float(zwerg)/10.0;
                    Serial.print("Temp: ");
                    Serial.println(fzwerg,1);
                    valToSend += "&T=" + String(fzwerg);
                    break;
        case 0x02:  i+=2;
                    zwerg = (rcv_arr[i] | (rcv_arr[i-1] << 8));
                    fzwerg = float(zwerg)/10.0;
                    Serial.print("Hum: ");
                    Serial.println(fzwerg,1);
                    valToSend += "&H=" + String(fzwerg);
                    break;
        case 0x03:  i+=2;
                    zwerg = (rcv_arr[i] | (rcv_arr[i-1] << 8));
                    fzwerg = float(zwerg)/10.0;
                    Serial.print("Press: ");
                    Serial.println(fzwerg,1);
                    valToSend += "&P=" + String(fzwerg);
                    break;
        case 0x04:  i+=2;
                    zwerg = (rcv_arr[i] | (rcv_arr[i-1] << 8));
                    fzwerg = float(zwerg)/10.0;
                    Serial.print("Water: ");
                    Serial.println(fzwerg,1);
                    valToSend += "&W=" + String(fzwerg);
                    break;            
        case 0x05:  if(mod_id < 0xA0)
                    {
                      i++;
                      Serial.print("Batt: ");
                      Serial.println(rcv_arr[i]);
                      valToSend += "&B=" + String(rcv_arr[i],DEC);
                    }
                    else
                    {
                      i+=2;
                      zwerg = (rcv_arr[i] | (rcv_arr[i-1] << 8));
                      fzwerg = float(zwerg)/100.0;
                      Serial.print("Batt: ");
                      Serial.println(fzwerg,2);
                      valToSend += "&BF=" + String(fzwerg);
                    }
                    break;
        case 0x06:  i+=2;
                    zwerg = (rcv_arr[i] | (rcv_arr[i-1] << 8));
                    fzwerg = float(zwerg);
                    Serial.print("UV: ");
                    Serial.println(zwerg);
                    valToSend += "&UV=" + String(zwerg,DEC);
                    break;
        case 0x07:  i+=2;
                    zwerg = (rcv_arr[i] | (rcv_arr[i-1] << 8));
                    fzwerg = float(zwerg);
                    Serial.print("Rain: ");
                    Serial.println(zwerg);
                    valToSend += "&RA=" + String(zwerg,DEC);
                    break;
        case 0x0D:  if(mod_id < 0xA0)
                    {
                      i++;
                      Serial.print("Runtime: ");
                      Serial.println(rcv_arr[i]);
                      valToSend += "&RT=" + String(rcv_arr[i],DEC);
                    }
                    else
                    {
                      i+=2;
                      zwerg = (rcv_arr[i] | (rcv_arr[i-1] << 8));
                      Serial.print("Runtime: ");
                      Serial.println(zwerg);
                      valToSend += "&RT=" + String(zwerg,DEC);
                    }                 
                    break;
        case 0x0E:  //delay(100);
                    radio.stopListening();
                    tx_remain = getRemain(mod_id);
                    txAddr[0] = mod_id;
                    tx_arr[1] = mod_id;
                    tx_arr[3] = msb(tx_remain);
                    tx_arr[4] = lsb(tx_remain);
                    txAddr[0] = mod_id;
                    radio.openWritingPipe(txAddr);
                    Serial.println("Sending..");
                    if(!radio.write(&tx_arr, sizeof(tx_arr)))
                    { Serial.println("T1");
                      delay(100);
                      if(!radio.write(&tx_arr, sizeof(tx_arr)))
                      {Serial.println("T2");
                        delay(100);
                        if(!radio.write(&tx_arr, sizeof(tx_arr)))
                        {Serial.println("T3");
                          delay(100);
                        }
                      }
                    }
                    radio.startListening();
                    break;
        case 0x08:  Serial.println("Gauge Int!");
                    valToSend += "&GA=1";
                    break;
        case 0xFF:  Serial.println("End");
                    rcvCorr = 1;
                    i = 36;
                    break;
        default:    Serial.println("Error decoding!");
                    rcvCorr = 0;
                    i=36;
      }
    }
    
    Serial.println("_____________");
    Serial.println("Finished");
    Serial.println("_____________");
    Serial.println("");

    if(rcvCorr)
    {
      Serial.println(valToSend);
      callUpdate(valToSend);
      Serial.println("_____________");
      Serial.println("");
      
    }
    else
    {
      Serial.println("Print Error");
    }
  }
}
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

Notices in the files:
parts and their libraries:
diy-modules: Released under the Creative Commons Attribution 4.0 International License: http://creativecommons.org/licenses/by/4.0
